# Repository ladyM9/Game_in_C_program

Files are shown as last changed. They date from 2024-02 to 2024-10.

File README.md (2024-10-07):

# Game_in_C_program
This project is based on the STM32H742ZIT6, with games displayed on the TFT LCD display.
The menu is navigated using a joystick, and the games are played using an accelerometer.

 In this repository, you can find a scaling script (written in Python) for scaling a maze for display on an LCD TFT, as well as the main code used to display the menu and games. Other parts of the code describe the menu, the first game, the second game, and the objects in the games.

## ***Contents of repo***
-   Main code
-   Maze scaling script
-   Schema and PCB

## ***Features***
-   Two games
-   Power with using battery
-   Controlling with objects in games using the acelerometer
-   The history of game scores

## ***Game console overview***

<p align="center">
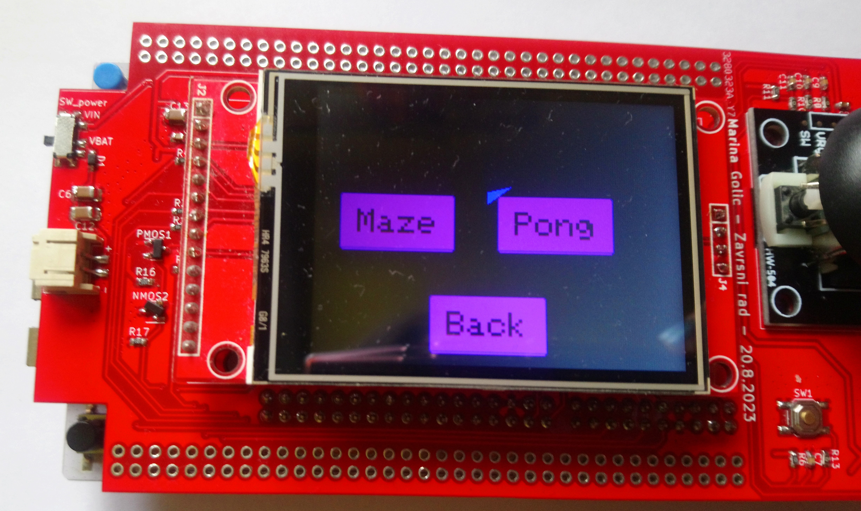
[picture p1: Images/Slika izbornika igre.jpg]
    
    <br>
        <b>Main Menu Overview</b>
</p>
<br>

<p align="center">
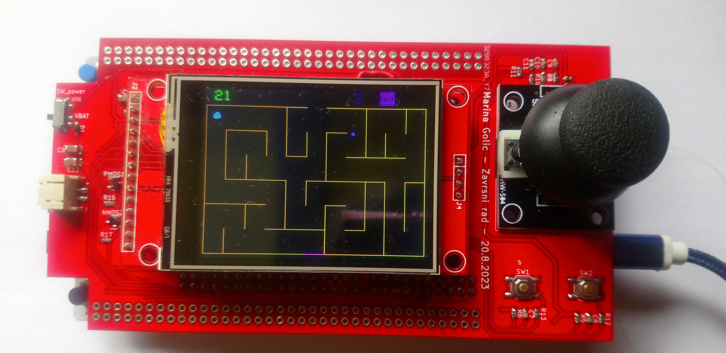
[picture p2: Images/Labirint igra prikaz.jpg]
    
    <br>
        <b>Maze game</b>
</p>
<br>

<p align="center">
    
    <br>
        <b>Pong game</b>
</p>
<br>

<p align="center">
    
    <br>
        <b>Highscore screen</b>
</p>
<br>

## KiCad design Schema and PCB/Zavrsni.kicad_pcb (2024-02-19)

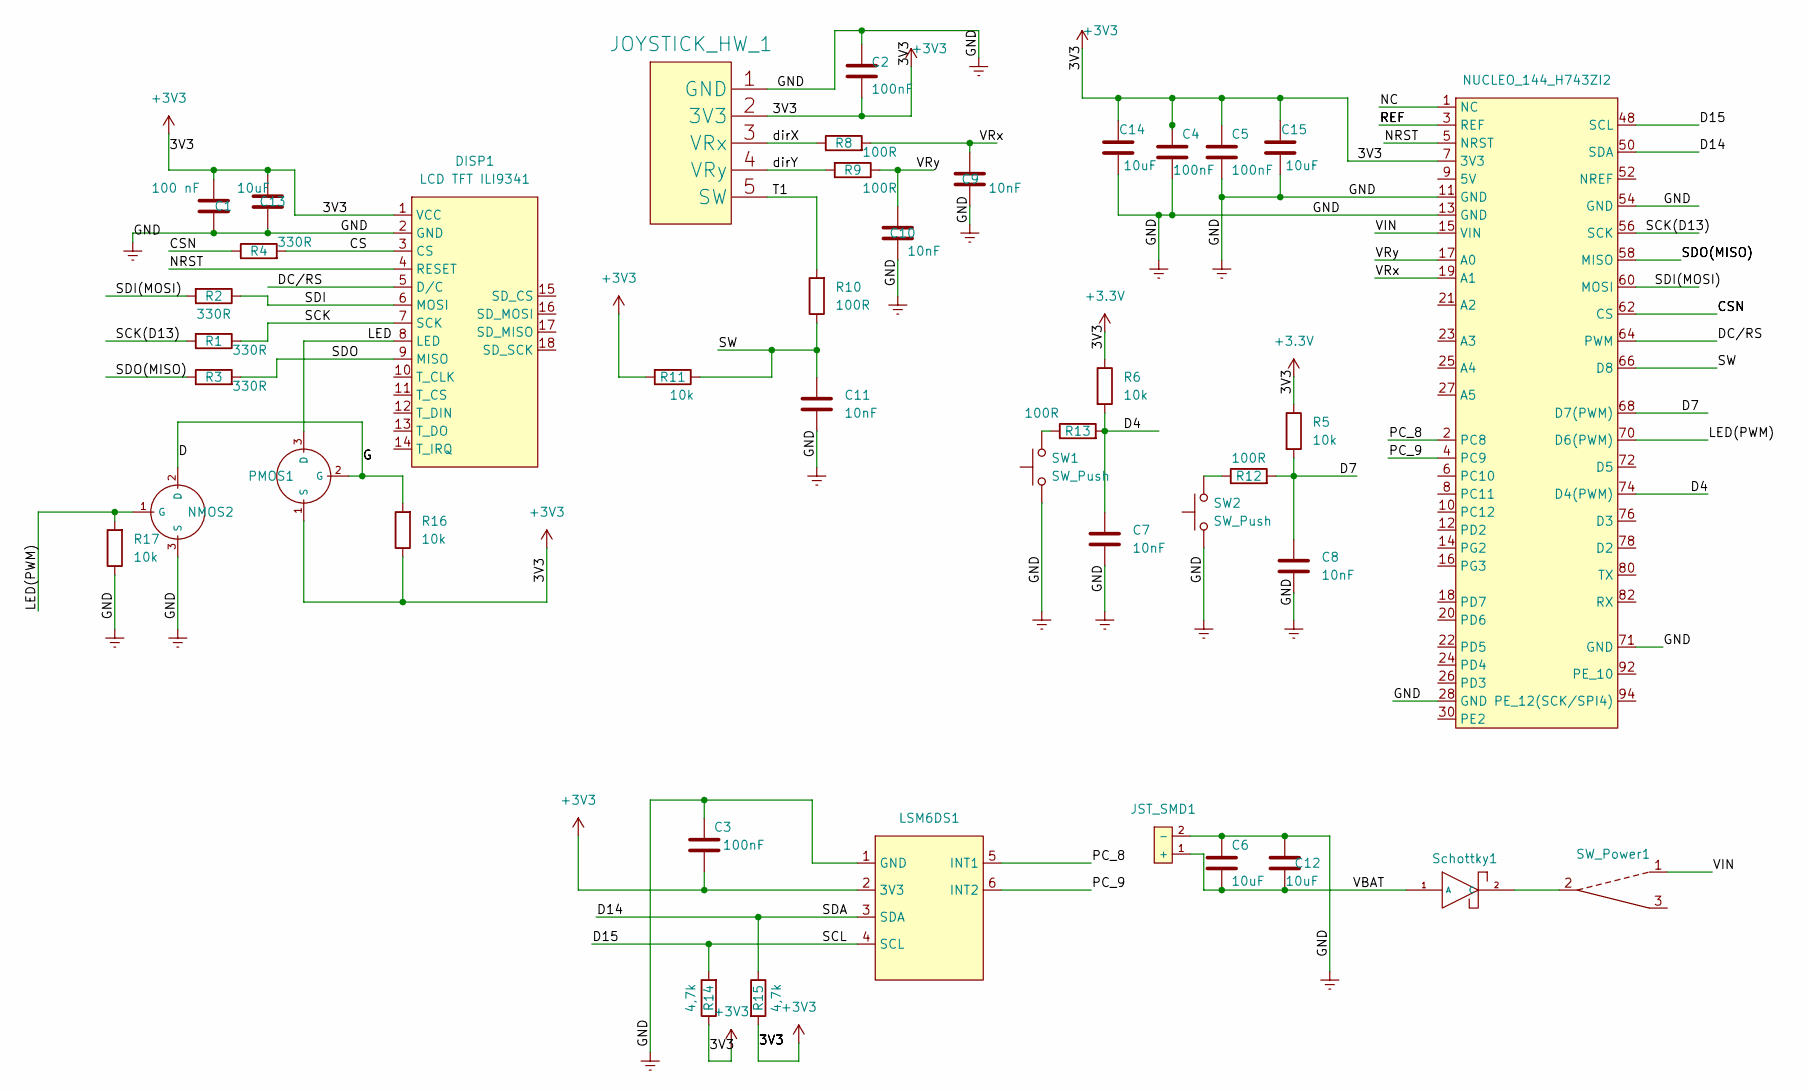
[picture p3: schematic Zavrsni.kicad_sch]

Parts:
C1: 100 nF; C_0603_1608Metric
C2, C3, C4, C5: 100nF; C_0603_1608Metric
C6, C12, C13, C14, C15: 10uF; C_1206_3216Metric
C7, C8, C9, C10, C11: 10nF; C_0603_1608Metric
DISP1: LCD TFT ILI9341; LCD_TFT_2.4
JOYSTICK_HW_1: JOYSTICK
JST_SMD1: JST_SMD
LSM6DS1: LSM6DS3
NMOS2: SOT-23-3
NUCLEO_144_H743ZI2: NUCLEO_PCB
PMOS1: SOT-23-3
R1, R2, R3, R4: 330R; R_0603_1608Metric
R5, R6: 10k; C_0603_1608Metric
R8, R9, R10, R12, R13: 100R; R_0603_1608Metric
R11, R16, R17: 10k; R_0603_1608Metric
R14, R15: 4,7k; R_0603_1608Metric
SW1, SW2: SW_Push; SW_SPST_SKQG_WithoutStem
SW_Power1: Power_Switch
Schottky1: Schottky_D

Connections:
+3.3V: C1.1, C2.2, C3.2, C4.1, C5.1, C13.2, C14.1, C15.1, DISP1.1 (VCC), JOYSTICK_HW_1.2 (3V3), LSM6DS1.2 (3V3), NUCLEO_144_H743ZI2.7 (3V3), PMOS1.1 (S), R5.1, R6.1, R11.2, R14.1, R15.2, R16.1
/CS: DISP1.3 (CS), R4.2
/CSN: NUCLEO_144_H743ZI2.62 (CS), R4.1
/D: NMOS2.2 (D), PMOS1.2 (G), R16.2
/D4: C7.1, NUCLEO_144_H743ZI2.74 (D4(PWM)), R6.2, R13.2
/D7: C8.1, NUCLEO_144_H743ZI2.68 (D7(PWM)), R5.2, R12.2
/D14: LSM6DS1.3 (SDA), NUCLEO_144_H743ZI2.50 (SDA), R15.1
/D15: LSM6DS1.4 (SCL), NUCLEO_144_H743ZI2.48 (SCL), R14.2
/DC/RS: DISP1.5 (D/C), NUCLEO_144_H743ZI2.64 (PWM)
/LED: DISP1.8 (LED), PMOS1.3 (D)
/LED(PWM): NMOS2.1 (G), NUCLEO_144_H743ZI2.70 (D6(PWM)), R17.2
/NC: NUCLEO_144_H743ZI2.1 (NC)
/NRST: DISP1.4 (RESET), NUCLEO_144_H743ZI2.5 (NRST)
/PC_8: LSM6DS1.5 (INT1), NUCLEO_144_H743ZI2.2 (PC8)
/PC_9: LSM6DS1.6 (INT2), NUCLEO_144_H743ZI2.4 (PC9)
/REF: NUCLEO_144_H743ZI2.3 (REF)
/SCK: DISP1.7 (SCK), R1.1
/SCK(D13): NUCLEO_144_H743ZI2.56 (SCK), R1.2
/SDI: DISP1.6 (MOSI), R2.1
/SDI(MOSI): NUCLEO_144_H743ZI2.60 (MOSI), R2.2
/SDO: DISP1.9 (MISO), R3.2
/SDO(MISO): NUCLEO_144_H743ZI2.58 (MISO), R3.1
/SW: C11.1, NUCLEO_144_H743ZI2.66 (D8), R10.1, R11.1
/T1: JOYSTICK_HW_1.5 (SW), R10.2
/VBAT: C6.2, C12.2, JST_SMD1.1 (+), Schottky1.1 (A); also elsewhere on the board
/VIN: NUCLEO_144_H743ZI2.15 (VIN), SW_Power1.1
/VRx: C9.1, NUCLEO_144_H743ZI2.19 (A1), R8.2
/VRy: C10.1, NUCLEO_144_H743ZI2.17 (A0), R9.1
/dirX: JOYSTICK_HW_1.3 (VRx), R8.1
/dirY: JOYSTICK_HW_1.4 (VRy), R9.2
Earth: C1.2, C2.1, C3.1, C4.2, C5.2, C6.1, C7.2, C8.2, C9.2, C10.2, C11.2, C12.1, C13.1, C14.2, C15.2, DISP1.2 (GND), JOYSTICK_HW_1.1 (GND), JST_SMD1.2 (-), LSM6DS1.1 (GND), NMOS2.3 (S), NUCLEO_144_H743ZI2.11 (GND), NUCLEO_144_H743ZI2.13 (GND), NUCLEO_144_H743ZI2.28 (GND), NUCLEO_144_H743ZI2.54 (GND), NUCLEO_144_H743ZI2.71 (GND), R17.1, SW1.1, SW2.1
unnamed: R12.1, SW2.2
unnamed: R13.1, SW1.2
unnamed 33: SW_Power1.2, Schottky1.2 (C); also elsewhere on the board

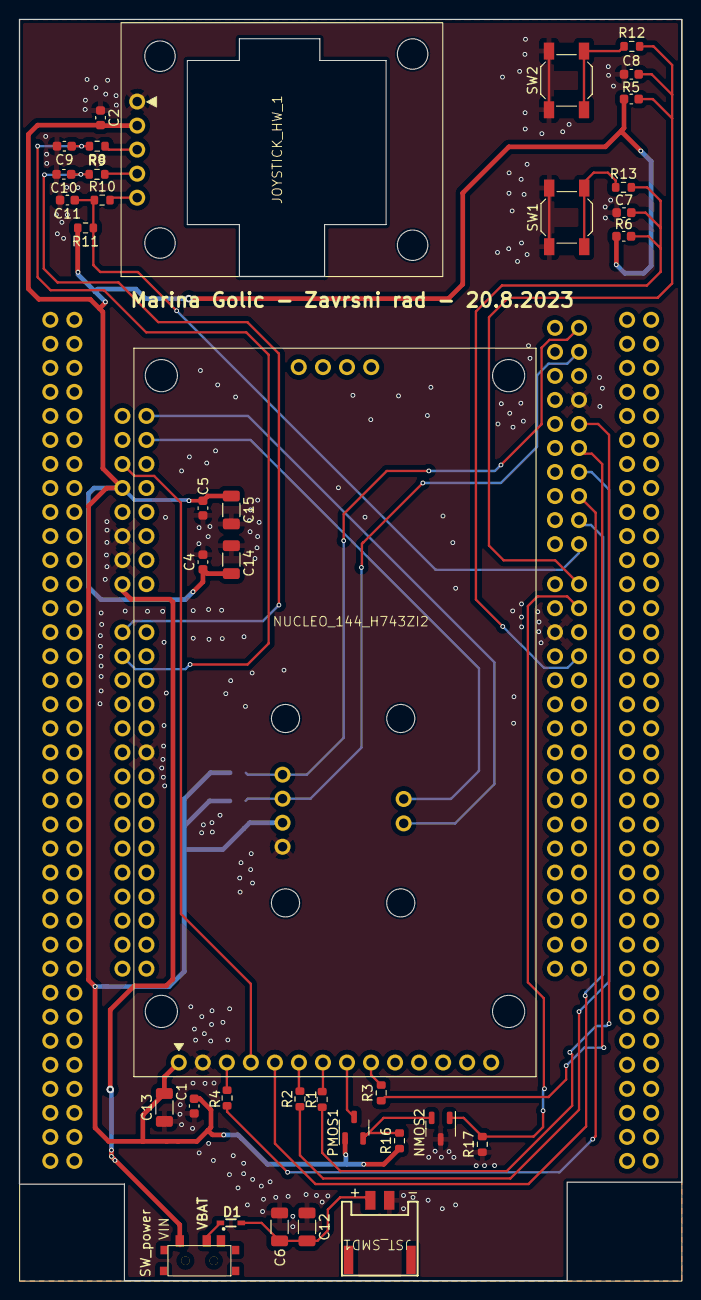
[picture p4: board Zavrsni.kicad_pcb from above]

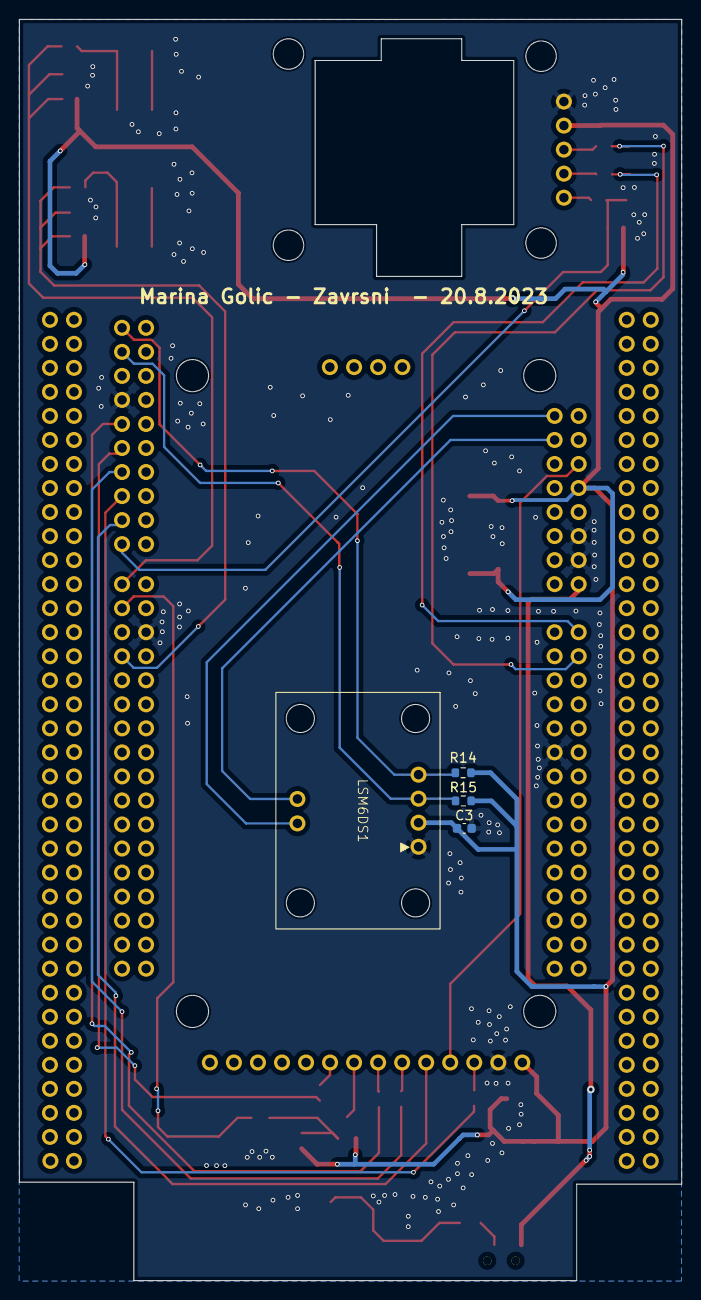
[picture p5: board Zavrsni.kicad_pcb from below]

Board: 2 copper layers, 70.0 x 133.3 mm, 42 parts (4 on the bottom side), 32 nets.

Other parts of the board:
D1: Schottky_D

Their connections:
/VBAT: D1.1 (A); also elsewhere on the board
unnamed 33: D1.2 (C); also elsewhere on the board

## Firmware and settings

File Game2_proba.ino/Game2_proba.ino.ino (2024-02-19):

#include "Adafruit_GFX.h"
#include "ILI9341_STM32.h"
#include "defines.h"
#include "labirint.h"

#define TFT_DC 9
#define TFT_CS 10
Adafruit_ILI9341 display = Adafruit_ILI9341(TFT_CS, TFT_DC);

int x;
int SW = 2;
int SW_state = 0;
int z = 0;
bool ref = false;
bool time_game = false;

myline_t myline; // tip podatka
OBJECT_t OBJECT1;


// uint8_t myline = labirint[55][4];


void setup()
{
    // put your setup code here, to run once:
    pinMode(A0, INPUT);
    pinMode(A1, INPUT);

    Serial.begin(115200);
    display.begin();
    display.setRotation(1);
    display.clearDisplay();
    display.setTextWrap(false);
    display.setTextSize(4);
    display.setTextColor(ILI9341_BLUE);
    start_game(OBJECT1, ILI9341_WHITE);
    display.display();
}

void loop()
{
    // put your main code here, to run repeatedly:
    int rawX = 1023 - analogRead(A0);
    int rawY = 1023 - analogRead(A1);

    int labSelect = random(0, 1); // Varijabla pomoću koje se ispisuje random labirint na zaslon


    if (rawX < 500 || rawX > 520)
    {
        OBJECT1.xOld = OBJECT1.x;
        OBJECT1.x += (511 - rawX) / 100;
        if (OBJECT1.x > 319)
            OBJECT1.x = 319;
        if (OBJECT1.x < 0)
            OBJECT1.x = 0;
        ref = true;
    }
    if (rawY < 500 || rawY > 520)
    {
        OBJECT1.yOld = OBJECT1.y;
        OBJECT1.y += (511 - rawY) / 100;

        if (OBJECT1.y > 239)
            OBJECT1.y = 239;
        if (OBJECT1.y < 0)
            OBJECT1.y = 0;
        ref = true;
    }
    if (ref == true)
    {
        ref = false;
        int col = checkCollision(OBJECT1, myLabs[labSelect] , 50);
        int col_1 = checkPoint(OBJECT1, myLabs[labSelect] ,50);
        display.clearDisplay();
        // drawLines(myLabs[labSelect], labElements[labSelect], ILI9341_WHITE); // ispis labirinta, dakle prvi argument
        // je koji lab, drugi broj linija i treći boja
        drawCircle(OBJECT1, ILI9341_WHITE);
        if (col == 0)
        {
            drawLines(myLabs[labSelect], labElements[labSelect], ILI9341_WHITE);
        }
        if (col != 0)
        {
           drawLines(myLabs[labSelect], labElements[labSelect], ILI9341_RED); 
        }
        if (col_1 != 0)
        {
            checkPoint(OBJECT1, myLabs[labSelect],50);
            OBJECT1.x = OBJECT1.xOld;
            OBJECT1.y = OBJECT1.yOld;
        }
        display.display();
    }
};

void drawLines(const myline_t *_m, int _bl, uint16_t _c)
{
    int col = 0;
    uint16_t color = ILI9341_WHITE;
    uint16_t color1 = ILI9341_RED;

    for (int i = 0; i < _bl; i++) // petlja za iscrtavanje svih linija u labirintu
    {
        display.drawLine(_m[i].x0, _m[i].y0, _m[i].x1, _m[i].y1, _c);
    };
}

void drawCircle(OBJECT_t _b, uint16_t _c)
{
    uint16_t color = ILI9341_WHITE;
    display.fillCircle(_b.x, _b.y, _b.r, ILI9341_WHITE);
}

void start_game(OBJECT_t _b, uint16_t _c) // poćetna pozicija kuglice kada se upali display
{
    OBJECT1.x = display.width() - 160;  //  početna pozicija kuglice po x osi
    OBJECT1.y = display.height() - 242; // početna pozicija kuglice po y osi
}
uint8_t checkPoint( OBJECT_t _b, const myline_t * _l, int _n)
{
  uint8_t _dc = 0;
  for ( int i = 0; i < _n; i++)
  {
    int _w = abs(_l[i].x1  - _l[i].x0);
    int _h = abs(_l[i].y1   - _l[i].y0);
    int _x = _l[i].x0   >= _l[i].x1   ? _l[i].x1   : _l[i].x0  ;  // ovo si prije radila u void loop petlji sa ispitivanjem if (col %ss 1) i ( col % 2)
    int _y = _l[i].y0   >= _l[i].y1   ? _l[i].y1   : _l[i].y0  ;
    if ((_w != 0) && (_b.x >= _x) && (_b.x < (_x + _w)))
    {
      if (((_b.yOld >= _y) && (_b.y <= _y)) || (_b.yOld <= _y) && (_b.y >= _y)) _dc |= 1;

    }
    if ((_h != 0) && (_b.y >= _y) && (_b.y < (_y + _h)))
    {
      if (((_b.xOld >= _x) && (_b.x <= _x)) || ((_b.xOld <= _x) && (_b.x >= _x))) _dc |= 2;

    }//return _dc;
  }
  return _dc;
}

uint8_t checkCollision(OBJECT_t _b, const myline_t *_l, int _n) //detekcija kolizije, odnosno da li je objekt dodirnuo liniju u labirintu
{
    uint8_t _cd = 0;

    for (int i = 0; i < _n; i++)
    {
        int _w = abs(_l[i].x1 - _l[i].x0);
        int _h = abs(_l[i].y1 - _l[i].y0);
        int _x = _l[i].x0 >= _l[i].x1
                     ? _l[i].x1
                     : _l[i].x0; // ovo si prije radila u void loop petlji sa ispitivanjem if (col %ss 1) i ( col % 2)
        int _y = _l[i].y0 >= _l[i].y1 ? _l[i].y1 : _l[i].y0;
        if ((_w != 0) && (_b.x >= _x) && (_b.x < (_x + _w)))
        {
            if (((_b.yOld >= _y) && (_b.y <= _y)) || (_b.yOld <= _y) && (_b.y >= _y))
                _cd |= 1;
        }
        if ((_h != 0) && (_b.y >= _y) && (_b.y < (_y + _h)))
        {
            if (((_b.xOld >= _x) && (_b.x <= _x)) || ((_b.xOld <= _x) && (_b.x >= _x)))
                _cd |= 2;
        }
    }
    return _cd;
}

extern "C" void SystemClock_Config(void)
{
    RCC_OscInitTypeDef RCC_OscInitStruct = {0};
    RCC_ClkInitTypeDef RCC_ClkInitStruct = {0};
    RCC_PeriphCLKInitTypeDef PeriphClkInitStruct = {0};

    /** Supply configuration update enable
     */
    HAL_PWREx_ConfigSupply(PWR_LDO_SUPPLY);
    /** Configure the main internal regulator output voltage
     */
    __HAL_PWR_VOLTAGESCALING_CONFIG(PWR_REGULATOR_VOLTAGE_SCALE0);

    while (!__HAL_PWR_GET_FLAG(PWR_FLAG_VOSRDY))
    {
    }
    /** Initializes the CPU, AHB and APB busses clocks
     */
    RCC_OscInitStruct.OscillatorType = RCC_OSCILLATORTYPE_HSI48 | RCC_OSCILLATORTYPE_HSE;
    RCC_OscInitStruct.HSEState = RCC_HSE_BYPASS;
    RCC_OscInitStruct.HSI48State = RCC_HSI48_ON;
    RCC_OscInitStruct.PLL.PLLState = RCC_PLL_ON;
    RCC_OscInitStruct.PLL.PLLSource = RCC_PLLSOURCE_HSE;
    RCC_OscInitStruct.PLL.PLLM = 1;
    RCC_OscInitStruct.PLL.PLLN = 120;
    RCC_OscInitStruct.PLL.PLLP = 2;
    RCC_OscInitStruct.PLL.PLLQ = 2;
    RCC_OscInitStruct.PLL.PLLR = 2;
    RCC_OscInitStruct.PLL.PLLRGE = RCC_PLL1VCIRANGE_3;
    RCC_OscInitStruct.PLL.PLLVCOSEL = RCC_PLL1VCOWIDE;
    RCC_OscInitStruct.PLL.PLLFRACN = 0;
    if (HAL_RCC_OscConfig(&RCC_OscInitStruct) != HAL_OK)
    {
        Error_Handler();
    }
    /** Initializes the CPU, AHB and APB busses clocks
     */
    RCC_ClkInitStruct.ClockType = RCC_CLOCKTYPE_HCLK | RCC_CLOCKTYPE_SYSCLK | RCC_CLOCKTYPE_PCLK1 |
                                  RCC_CLOCKTYPE_PCLK2 | RCC_CLOCKTYPE_D3PCLK1 | RCC_CLOCKTYPE_D1PCLK1;
    RCC_ClkInitStruct.SYSCLKSource = RCC_SYSCLKSOURCE_PLLCLK;
    RCC_ClkInitStruct.SYSCLKDivider = RCC_SYSCLK_DIV1;
    RCC_ClkInitStruct.AHBCLKDivider = RCC_HCLK_DIV2;
    RCC_ClkInitStruct.APB3CLKDivider = RCC_APB3_DIV2;
    RCC_ClkInitStruct.APB1CLKDivider = RCC_APB1_DIV2;
    RCC_ClkInitStruct.APB2CLKDivider = RCC_APB2_DIV2;
    RCC_ClkInitStruct.APB4CLKDivider = RCC_APB4_DIV2;

    if (HAL_RCC_ClockConfig(&RCC_ClkInitStruct, FLASH_LATENCY_4) != HAL_OK)
    {
        Error_Handler();
    }
    PeriphClkInitStruct.PeriphClockSelection = RCC_PERIPHCLK_SPI1 | RCC_PERIPHCLK_USB | RCC_PERIPHCLK_FMC;
    PeriphClkInitStruct.FmcClockSelection = RCC_FMCCLKSOURCE_D1HCLK;
    PeriphClkInitStruct.Spi123ClockSelection = RCC_SPI123CLKSOURCE_PLL;
    PeriphClkInitStruct.UsbClockSelection = RCC_USBCLKSOURCE_HSI48;
    if (HAL_RCCEx_PeriphCLKConfig(&PeriphClkInitStruct) != HAL_OK)
    {
        Error_Handler();
    }
    /** Enable USB Voltage detector
     */
    HAL_PWREx_EnableUSBVoltageDetector();
}

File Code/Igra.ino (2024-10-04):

#include "Adafruit_GFX.h"
#include "ILI9341_STM32.h"
#include "SparkFunLSM6DS3.h"
#include "Wire.h"
#include "myDefines.h"
#include "ball.h"
#include "screen.h"
#include "pong.h"
#include "maze.h"
#include "GUI.h"
#include "lab.h"
#include "icons.h"

#define TFT_DC 9
#define TFT_CS 10
Adafruit_ILI9341 display = Adafruit_ILI9341(TFT_CS, TFT_DC);
LSM6DS3 myIMU(I2C_MODE, 0x6B); // Default constructor is I2C, addr 0x6B

Screen screen(&display);         // objekt klase Screen
Ball ball(&LCDforScreenRefresh); // objekt klase Ball
Button button(&LCDforScreenRefresh);
Maze maze; // objekt klase Maze
Pong pong(&LCDforScreenRefresh);
RNG_HandleTypeDef hrng = {0};

unsigned long Time = 0;
unsigned long Times = 0;
unsigned long game_over = 0;
unsigned long TIMER_CHANGE_INTERVAL = 50000;


int state = 0;
int brojanje_exit = 0;

myPaddle_t1 paddle_el[] = {30, 95, 5, 50};
myPaddle_t2 paddle_el2[] = {290, 95, 5, 50};
myPaddle_t1 *padle1[] = {paddle_el};
myPaddle_t2 *padle2[] = {paddle_el2};
my_ballPong pong_el[] = {160, 120, 3};
my_ballPong *ponggame[] = {pong_el};

void setup()
{

  pinMode(A0, INPUT);
  pinMode(A1, INPUT);
  pinMode(D8, INPUT_PULLUP);
  pinMode(USER_BTN, INPUT);
  pinMode(D6, OUTPUT);
  pinMode(D4, INPUT_PULLUP);
  digitalWrite(D6, HIGH);
 // digitalWrite(D8, HIGH);
  Wire.setSCL(D15);
  Wire.setSDA(D14);
  maze.initializeRNG(&hrng);
  display.begin();
  Wire.begin();
  display.setRotation(3); // rotiraj display
 // Serial.begin(115200);
  myIMU.begin();
  // Forsiraj da kod misli da je partija igrice pobjeđena da bi se učitao novi random maze.
  // state = 1;
}

void loop()
{

  switch (state)
  {
    case 0:
    {

      game_over = (millis() / 1000);
      state = 16;
      break;
    }
    
    case 1:
      {
        int x;
        int y;

        if (button.myButton(display, x, y, 100, 50, 100, 50, 3, "START", 1) == 1)
        {
          state = 2;
        }
        if (button.myButton(display, x, y, 80, 150, 200, 50, 3, "HIGH SCORE", 1) == 1)
        {
          state = 12;
        }
        button.cursor(display, 1);
        break;
      }
    case 2:
      {

        int x;
        int y;

        if (button.myButton(display, x, y, 20, 90, 100, 50, 3, "Maze", 1) == 1)
        {
          state = 3;
        }
        if (button.myButton(display, x, y, 160, 90, 100, 50, 3, "Pong", 1) == 1)
        {
          state = 9;
        }
        if (button.myButton(display, x, y, 100, 180, 100, 50, 3, "Back", 1) == 1)
        {
          state = 1;
        }
        button.cursor(display, 1);

        break;
      }
    case 3:
      {
        int x;
        int y;
        int mod1 = 0;
        int mod2 = 1;
        int mod3 = 2;

        if (button.myButton(display, x, y, 20, 20, 100, 50, 3, "Easy", 1) == 1) // ako je kliknuta tipka za easy tezinu igrice odi na state 2
        {
          mod1 = maze.choosing_Mode_Game(0);
          state = 5;
        }
       else if (button.myButton(display, x, y, 150, 20, 120, 50, 3, "Medium", 1) == 1)
        {
          mod2 = maze.choosing_Mode_Game(1);
          state = 5;
        }
       else if (button.myButton(display, x, y, 20, 100, 120, 50, 3, "Hard", 1) == 1)
        {
          mod3 = maze.choosing_Mode_Game(2);
          state = 5;
        }
       else if (button.myButton(display, x, y, 150, 100, 100, 50, 3, "Back", 1) == 1)
        {
          state = 1;
        }
        button.cursor(display, 1); // prikaz kurzora u izborniku za tezinu odabrane igrice

        break;
      }
    case 4:

      {
        int x;
        int y;
        GameLoop();
        if (button.back_Button(display, 270, 0, 20, 45, 2, "Back", 1) == true)
        {
          ball.reset_score();
          state = 3;
        }
        maze.drawLines(display); // iscrtaj labirint na display
        // Time_Game();             // iscrtaj i broji vrijeme u igrici
        if (Time_Game() == 1)
        {
          ball.Live(display);
          state = 5;
        }
        if (Time_Game() == 2)
        {
          state = 11;
        }

        if (ball.checkExit(display, maze.getCurrentMaze()) == true) // ako se kuglica nalazi na izlaznoj liniji iz labirinta odi na state
        {
          brojanje_exit += 1;
          ball.Bodovi_igra();
          state = 6;
        }


        break;
      }

    case 5:
      {
        maze.LoadNewMaze(maze.getRandomMaze(&hrng));            // ucitaj novi random labirint
        ball.firstBallposition(display, maze.getCurrentMaze()); // iscrtaj kuglicu na pocetnoj poziciji u odabranom labirintu
        Time = (millis() / 1000);                               // millis podjeli sa 1000 kako bi dobila odbrojavanje vremena u sekundama
        state = 4;                                              // odi na state 1 kako bi se odabrani random labirint iscrtao na display
        break;
      }

    case 6:
      {
        Times = (millis() / 1000);
        state = 7;

        break;
      }
    case 7:

      {
        ball.score_Game(display);
        if (brojanje_exit == 4)
        {
          state = 8;
          brojanje_exit = 0;
        }
        if (Time_Score() == true)
        {
          state = 5;
        }

        break;
      }
    case 8:
      {
        ball.win_Screen(display);
        if (Time_Score() == true)
        {
          state = 3;
        }
        break;
      }
    case 9:
      {

        pong.paddle1(display, padle1[0]);
        pong.paddle2(display, padle2[0]);


        state = 10;
        break;
      }
    case 10:
      {
        int x;
        int y;
        display.fillScreen(ILI9341_WHITE);
        pong.scoreInGame(display);
        pong.scoreInGame2(display);
        Game2();
        if (button.back_Button(display, 120, 0, 30, 50, 2 , "Back", 1) == true)
        {
          pong.reset_score();
          state = 1;
        }
        if (pong.GAME_OVER(display) == true)
        {
          state = 11;
        }

        break;
      }
    case 11:
      {
        game_over = (millis() / 1000);

        state = 15;
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

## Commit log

2022-02-23 Added custom STM32H743 clock config for faster SPI
2022-04-04 Added C code for extracting lab lines
    Converts lines from .svg file from www.mazegenerator.net into Arduino .h file with x1, y1, x2 and y2 coordinates.
2022-05-13 Problem with print game over on display
2023-01-21 Compile error fixed, added comments, code clean-up
    [Game2_proba.ino.ino]
2023-01-22 Fixed maze list / array name.
    [Game2_proba.ino.ino]
2023-01-23 Made collisions on lines and at checkpoints
    [Game2_proba.ino.ino]
2023-03-10 Fail...Nothing is print on display
    [Igra.ino]
2023-03-30 Problem with callback function
    [Igra.ino]
2023-04-04 Nothing is print to display with function callback
2023-04-20 Maze is print on display, but collision is not working
    [Igra.ino]
2023-04-21 Collision decetion on x direction
    [Igra.ino]
2023-05-03 Collision detection is not working on x os
    [Igra.ino, maze.cpp]
2023-05-11 Comments for code fix.
    [Igra.ino, maze.cpp]
2023-05-12 Added h file with maze, many error is corected
    [Igra.ino, maze.cpp]
2023-05-16 New code with correct detection collision
    [Igra.ino, maze.cpp]
2023-05-17 Added exit line and prepared text for printing time
2023-05-26 Added random number function and one more maze, but problem with time in game
    [Igra.ino]
2023-06-03 Adding intervals of time in game, but game is not work correctly, (ball is not moving)
    [Igra.ino, maze.cpp]
2023-06-06 Printing random maze on display after the collision between ball and exit line
    [Igra.ino, maze.cpp]
2023-06-13 Add switch case
2023-06-17 Finally fixed mazes switching after completing a maze, code clean-up, file clean-up.
    [Game2_proba.ino.ino, Igra.ino, maze.cpp]
2023-06-27 Finally a correct drawing of the maze with proper scaling
    [Igra.ino]
2023-07-22 [ladyM9] printing score screen, after the exit of maze
2023-07-29 Aceleometer is not working with SparkFunLSM6DS3 library
    [Igra.ino]
2023-07-31 fixed bug with game mode selection, extended output line, and added image representing the point that can be won in the game
    [Igra.ino, maze.cpp]
2023-08-04 Create Schema and PCB for game
2023-08-04 Schema and pcb for game
    [Zavrsni.kicad_pcb, Zavrsni.kicad_sch]
2023-08-06 Added push buttons, and footprint for JST connector
    [Zavrsni.kicad_sch]
2023-08-07 Start connecting the lines on the pcb
    [Zavrsni.kicad_pcb, Zavrsni.kicad_sch]
2023-08-11 [ladyM9] LSM is placed on the bottom side of the PCB, vias are reduced, buttons are placed and connected to the PCB
    [Zavrsni.kicad_pcb, Zavrsni.kicad_sch]
2023-08-12 All components on the PCB are connected
    [JOYSTICK.kicad_pcb, JOYSTICK.kicad_sch, Zavrsni.kicad_pcb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]
2023-08-13 Add power switch, poligon for GND, and flip lsm on bottom
    [Zavrsni.kicad_pcb, Zavrsni.kicad_sch]
2023-08-13 switch error, the wrong switch was selected and connected incorrectly in the schematic
    [Zavrsni.kicad_pcb, Zavrsni.kicad_sch]
2023-08-14 Shifted pins on the nucleo board, up the y axis
    [Zavrsni.kicad_pcb, Zavrsni.kicad_sch]
2023-08-16 The pcb is assembled, but the pin spacing is incorrect
    [Zavrsni.kicad_pcb, Zavrsni.kicad_sch]
2023-08-17 The pcb is cut for the buttons on the NUCLEO board
    [Zavrsni.kicad_pcb, Zavrsni.kicad_sch]
2023-08-19 Finnal version of PCB and schema
    [Zavrsni.kicad_pcb, Zavrsni.kicad_sch]
2023-08-19 Add collision detection in Pong game
    [Igra.ino]
2023-08-20 Finall version of PCB without gerbers
    [Zavrsni.kicad_pcb]
2023-09-15 After the push the back button, the menu has been open a
    And after 60 seconds in game, display the game over screen
2023-10-03 Fixed bug in pong game
    [GUI.cpp, Igra.ino]
2023-10-18 Files divided into folders
    [JOYSTICK.kicad_pcb, JOYSTICK.kicad_sch, Zavrsni.kicad_pcb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]
2024-02-19 Resolved problem with merge
    [GUI.cpp, Igra.ino]
2024-10-04 Bettter organization of files
    [JOYSTICK.kicad_pcb, JOYSTICK.kicad_sch, Zavrsni.kicad_pcb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]
